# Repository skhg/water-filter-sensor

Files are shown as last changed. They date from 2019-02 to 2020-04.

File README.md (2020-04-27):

# water-filter-sensor
A smart(er) ceramic water filter for my kitchen. This is the second version. [Here](./v1) you can see the first attempt.

## Concept
We use a [ceramic water filter](https://en.wikipedia.org/wiki/Ceramic_water_filter) at home for our drinking water and ice-making. Normally we try to keep it full, so there's always about 2L available at any time. However to be sure we haven't over-filled, we have to remove the top section to see how much is left in the bottom. Obviously, this minor effort is totally unacceptable, so I built a sensor system to tell us how full the tank is.

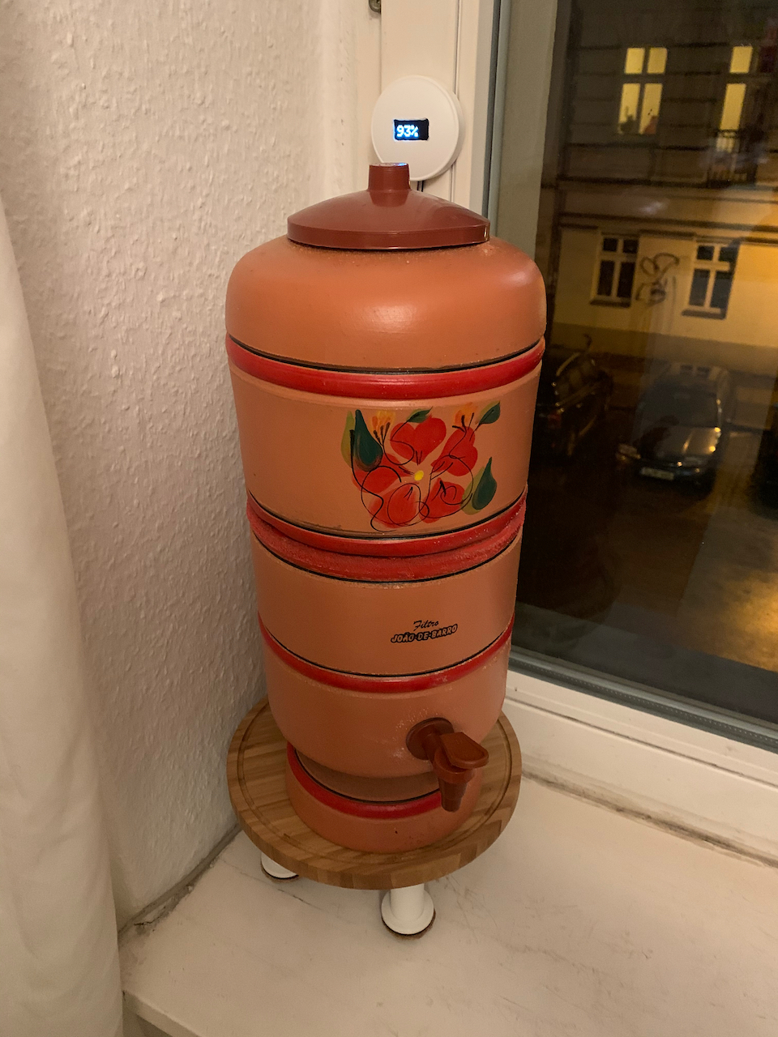
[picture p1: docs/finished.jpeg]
Finished project


Because i'm going totally overboard, it's also WiFi connected, remotely monitored and remotely configurable. Remote config/monitoring is done using my [household data logger](https://github.com/skhg/household-data-logger) project.

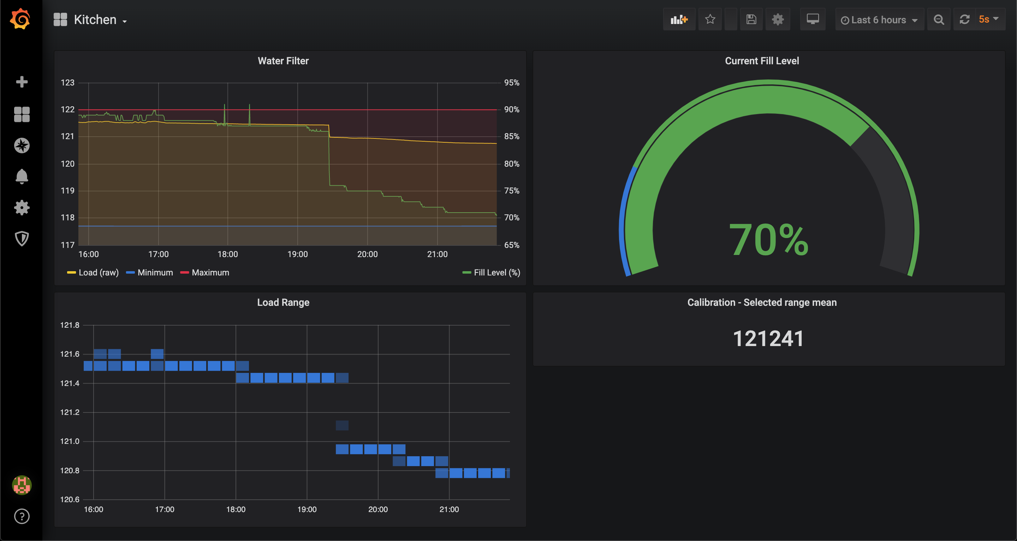
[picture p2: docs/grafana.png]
Grafana dashboard


## Overview
The water filter now sits on top of a circular wooden board, with adjustable legs I found in a waste bin at IKEA. Each leg has a HX-711 compatible load sensor glued to the bottom. Under the board, there's a plastic box to house the electronics. A longer ribbon cable extends up to eye level where a tiny OLED display shows the estimated fill percentage.

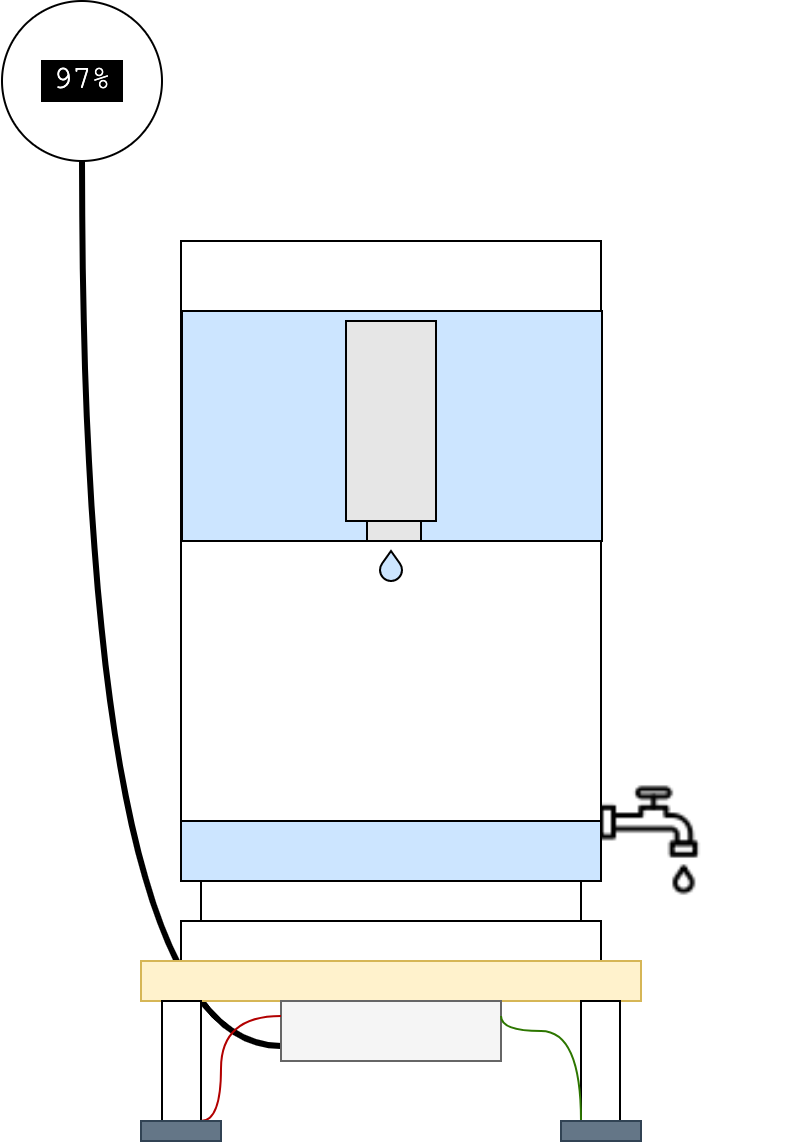
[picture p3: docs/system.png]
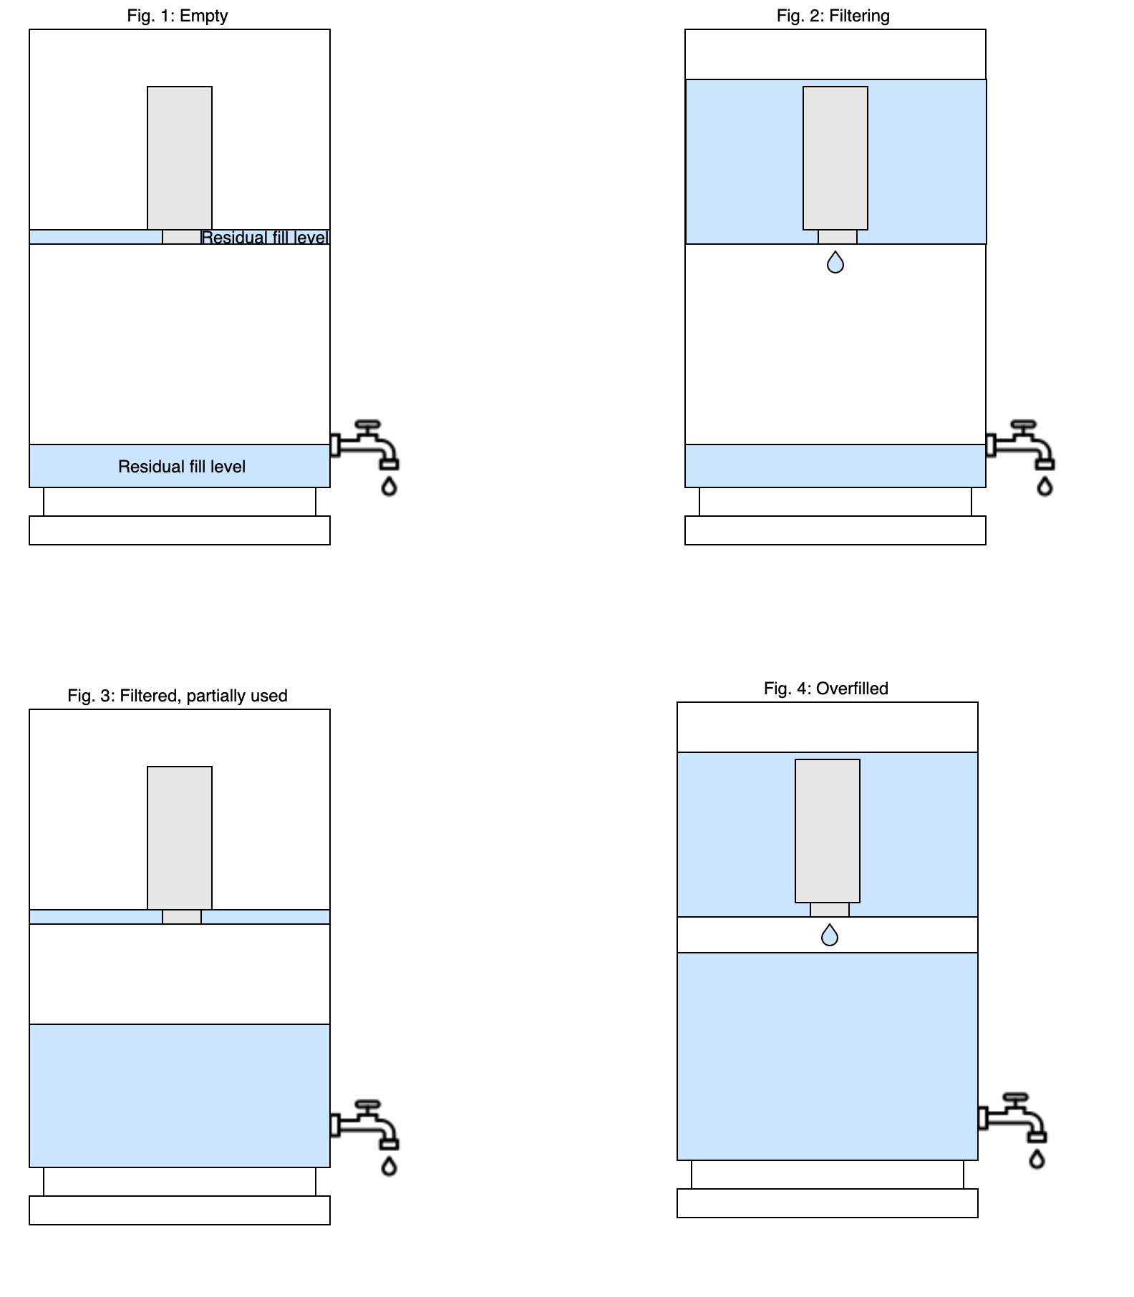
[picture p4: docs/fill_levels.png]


## Materials required
Electronics

* 1 [NodeMCU v3 ESP8266](https://www.amazon.de/-/en/gp/product/B074Q2WM1Y/ref=ppx_yo_dt_b_search_asin_title?ie=UTF8&psc=1)
* 1 HX-711 compatible [load sensor](https://www.amazon.de/gp/product/B075KKH416/ref=ppx_yo_dt_b_asin_title_o03__o00_s00?ie=UTF8&psc=1)
* 1 [OLED Screen](https://www.amazon.de/-/en/gp/product/B01L9GC470/ref=ppx_yo_dt_b_search_asin_title?ie=UTF8&psc=1)
* 1 set of 4 [load cells](https://www.amazon.de/-/en/Weissazi-Personal-Scales-Resistance-Measuring/dp/B07QB2DWMQ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) - I actually got mine from a broken bathroom scales.
* [Ribbon cable](https://www.amazon.de/gp/product/B076CLY8NH/ref=oh_aui_detailpage_o00_s00?ie=UTF8&psc=1)
* [Jumper pin connectors](https://www.amazon.de/gp/product/B01MRSUEHD/ref=oh_aui_detailpage_o01_s00?ie=UTF8&psc=1)

Other:

  * Soldering iron
  * 3rd hand
  * Bamboo board
  * Adjustable legs

## Connecting the load cells

Normally, load cells come with matching wire colours. Unfortunately the ones I scavenged from the old bathroom scale came with different 2 different sets of wire colours, so I had to manually work out which was which.

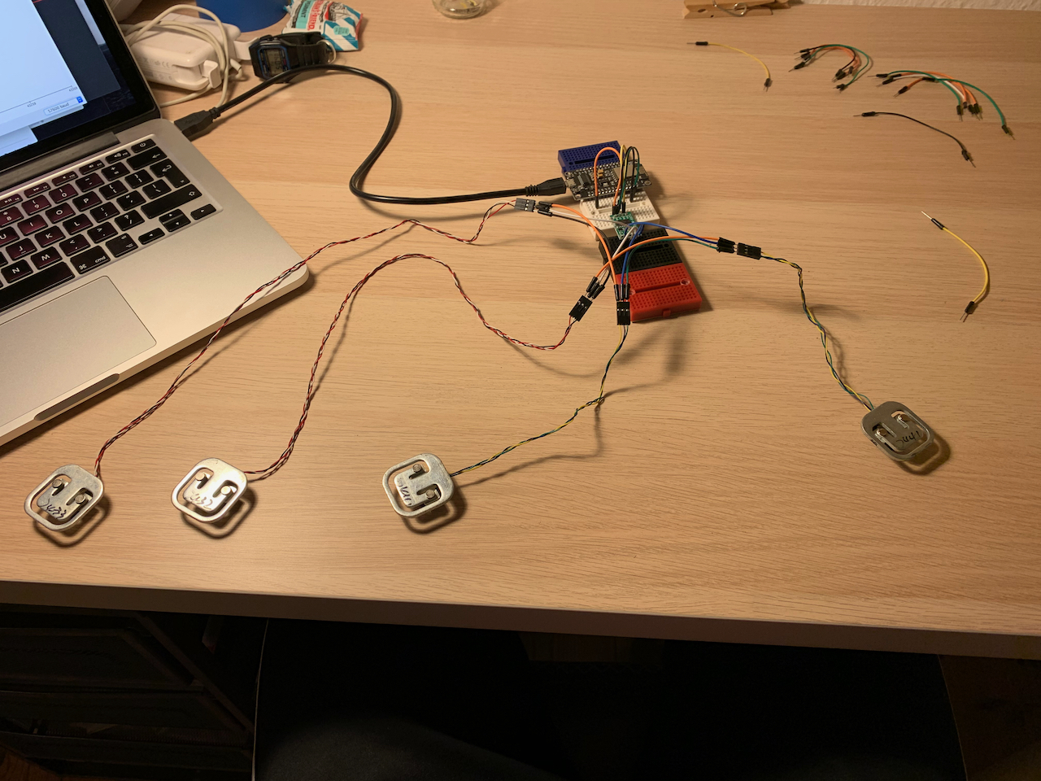
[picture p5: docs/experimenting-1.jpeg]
experimenting


Eventually I found [this diagram](http://blog.medien.ifi.lmu.de/swh/2018/09/10/hx711-how-to-measure-incorrectly/), and manually labelled the wires to match my own:

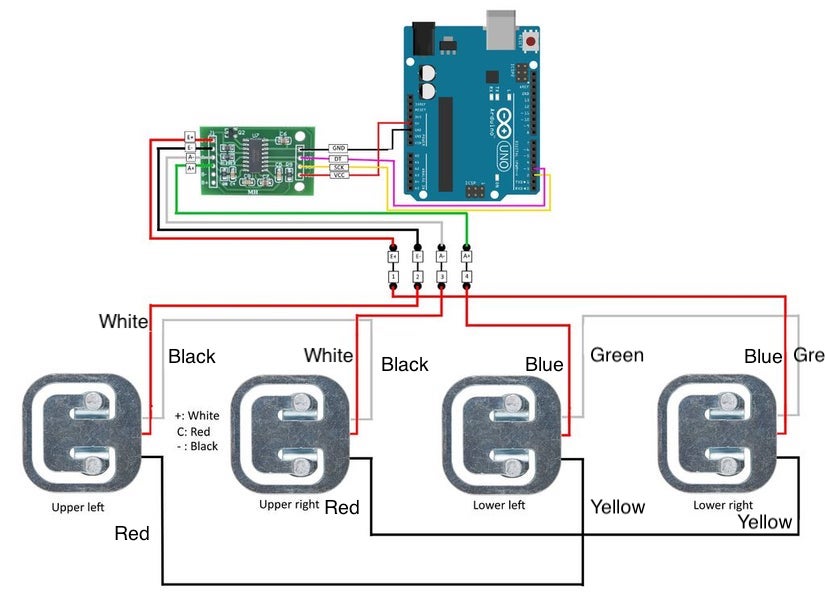
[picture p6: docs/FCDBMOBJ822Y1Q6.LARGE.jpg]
diagram


And got it wired up the same way...
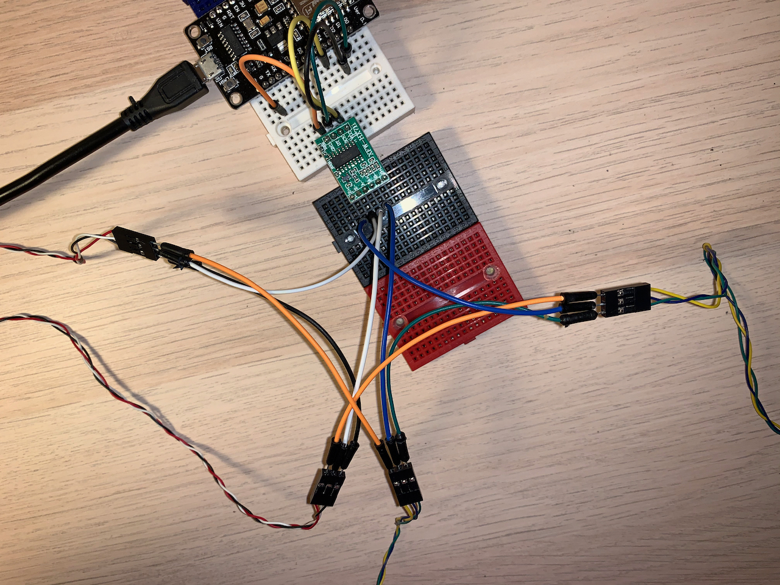
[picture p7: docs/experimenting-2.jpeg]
experimenting


Circuit diagram of the same thing, with the real world wire colours.

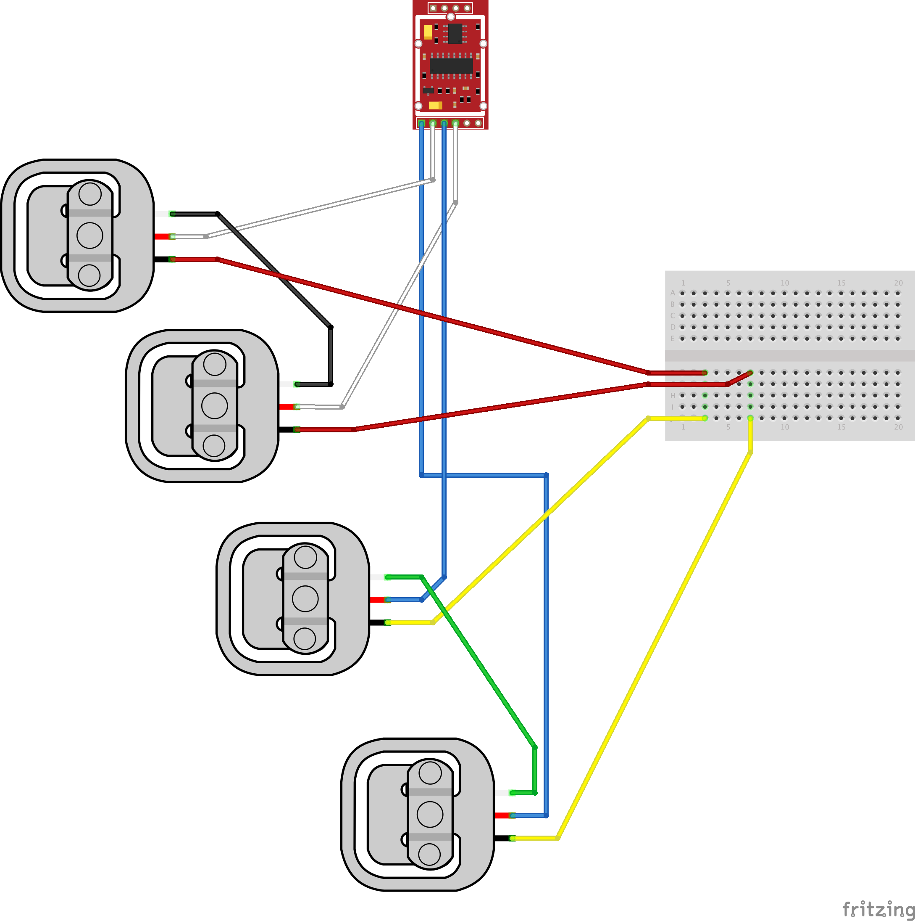
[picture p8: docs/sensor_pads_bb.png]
circuit


## Construction

The 4 sensors (should) evenly distribute the weight between each other. The [flexing](https://en.wikipedia.org/wiki/Load_cell) of the sensor as weight is applied is detected and converted to a load reading.

The load cells need a little space between themselves and the legs I used, so I glued some cork blocks in between, to allow the sensor space to flex.

Everything comes together in a little plastic box to make it a bit more protected from any nearby water splashes. 

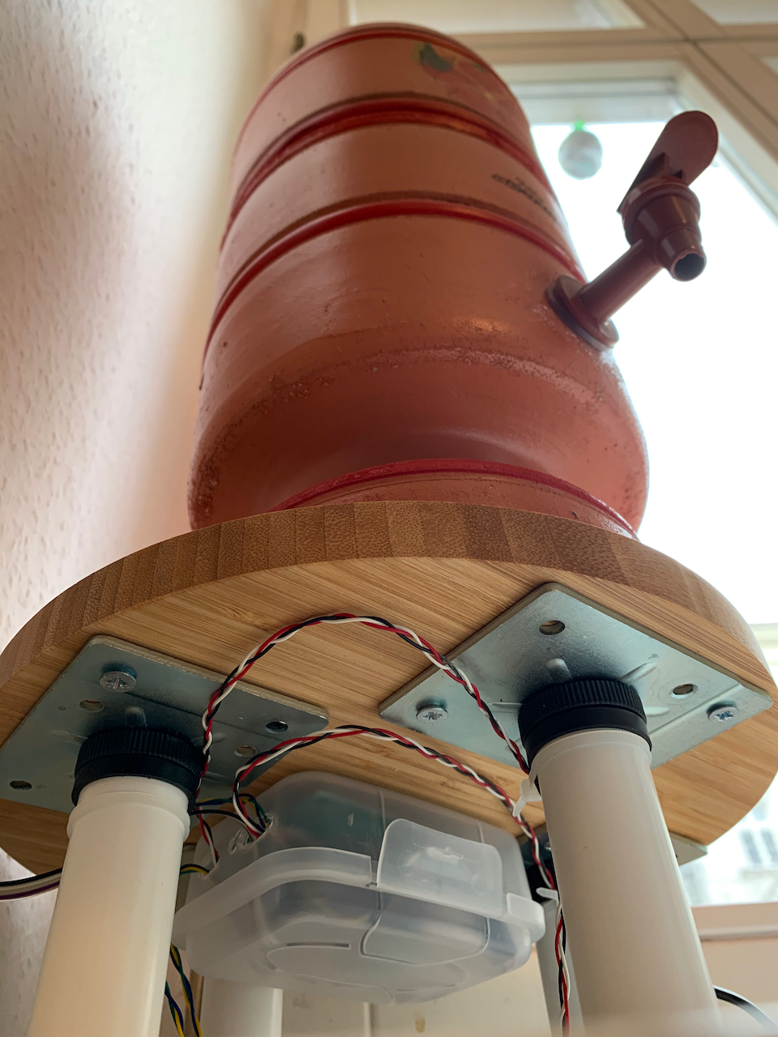
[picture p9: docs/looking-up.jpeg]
looking up


The screen is wedged inside the cap of an old moisturiser jar, just like I used for the [Raspberry Pi killswitch](https://github.com/skhg/raspberrypi-killswitch). These little plastic caps are really versatile for small projects. Since I didn't have any proper tools to cut a hole, I drew a rectangle on the front and melted a hole through it with my soldering iron. Probably toxic and not the best idea.
 
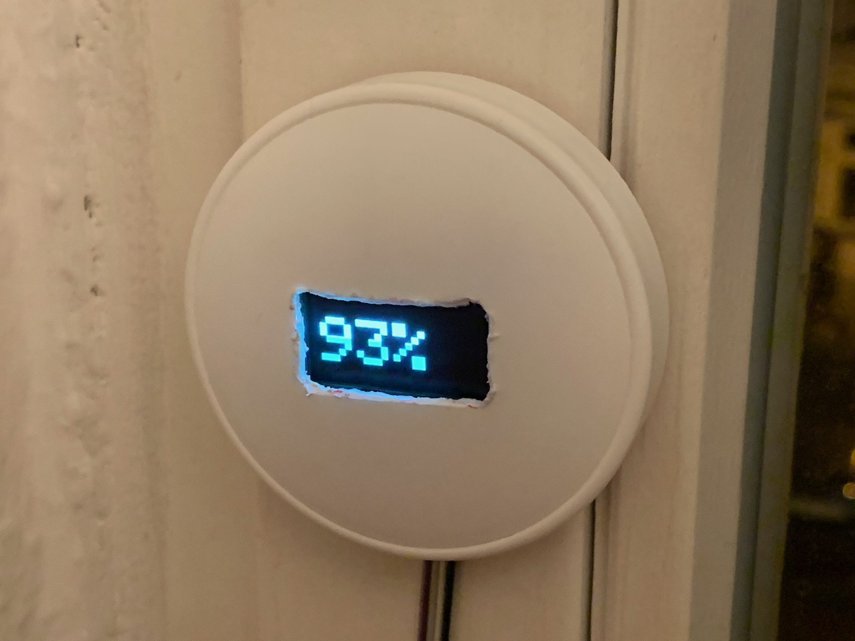
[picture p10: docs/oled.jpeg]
oled


## WiFi connection

### Calibration
For calibration, we need to know what reading the load sensor gives when the tank is empty, and when it's full. Then we can simply get the current reading and work out a percentage of the range. Normally, calibration would mean plugging the board into a laptop over USB, and uploading a new version of the `.ino` sketch with updated high/low values.

So instead, I use a `GET` endpoint on my [household data logger](https://github.com/skhg/household-data-logger) project, to return the current calibration values over HTTP. The filter looks them up automatically so they can be changed at any time. The message received from the server looks like:

```json
{
    "fullLevel" : 121000,
    "emptyLevel" : 117000
}
```

and the filter uses this to reset its own default values each time an update is received.

### Logging
The board also sends back it's current load level to the logger approximately every 2 seconds. This is also done using JSON over HTTP in a format that looks like

```json
{
    "load" : 1234.56,
    "fillPercentage" : 92.24
}
```

I record this in a time-series database and use it to create the Grafana dashboard shown at the top.

## Code
See the full Arduino C++ code in [water-filter-sensor.ino](water-filter-sensor.ino). 

Dependencies:
 * [movingAvg](https://github.com/JChristensen/movingAvg)
 * [Q2HX711](https://github.com/queuetue/Q2-HX711-Arduino-Library)
 * [home_wifi](https://github.com/skhg/home_wifi) configuration
 * [ArduinoJson](https://arduinojson.org/)
 * [ESP8266WiFi](https://github.com/esp8266/Arduino/tree/master/libraries/ESP8266WiFi)
 * [Adafruit_GFX](https://github.com/adafruit/Adafruit-GFX-Library)
 * [Adafruit_SSD1306](https://github.com/adafruit/Adafruit_SSD1306)

## Circuit

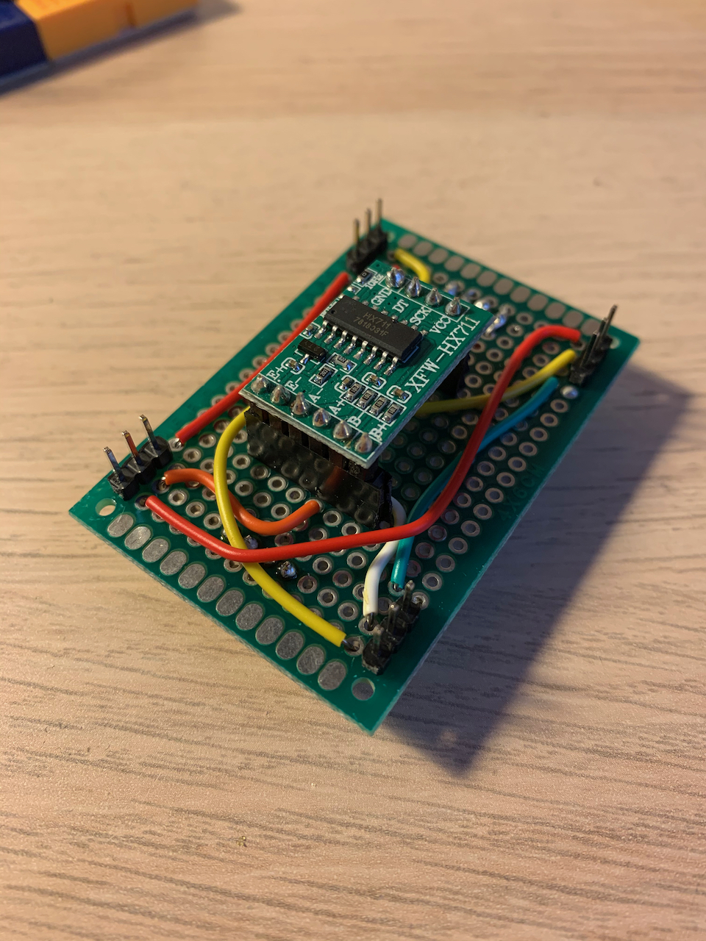
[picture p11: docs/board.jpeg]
board photo Circuit photo


The underside of this has the mounting pins for the Arduino board, but I forgot to take a photo.

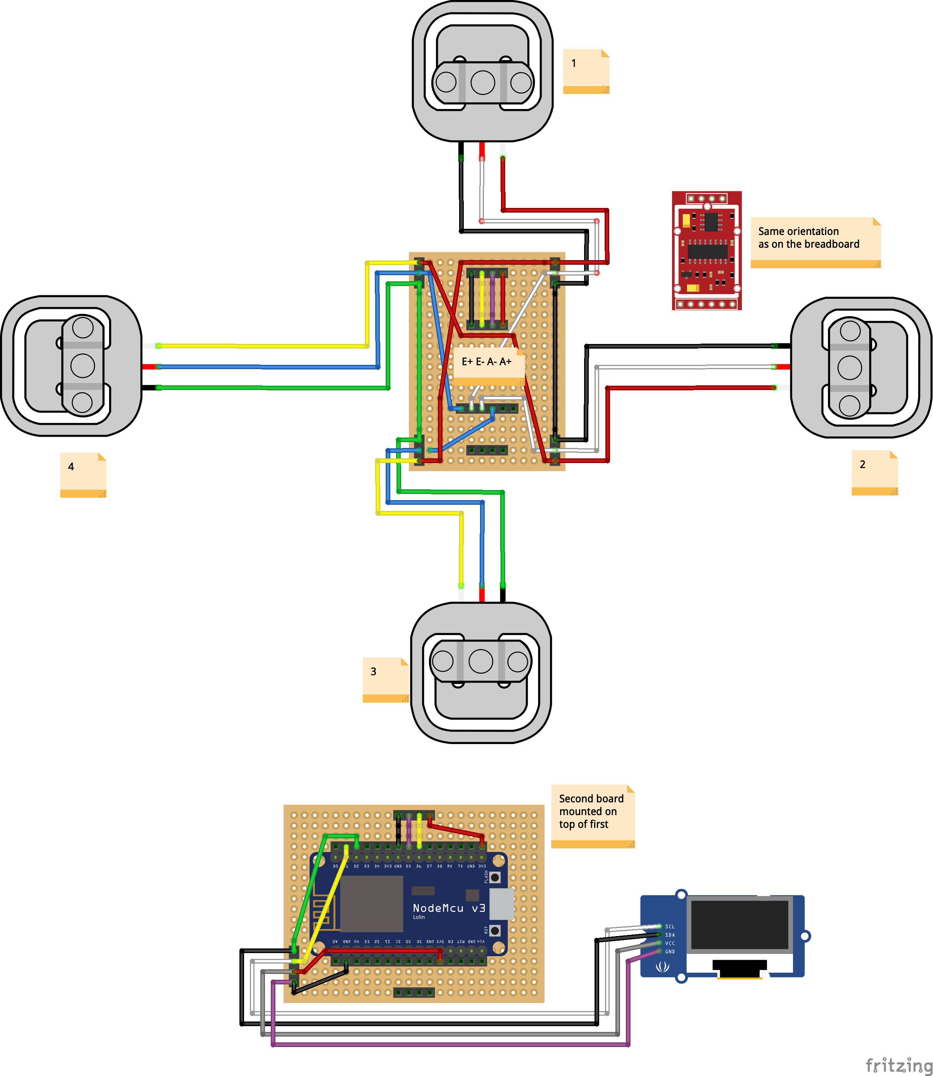
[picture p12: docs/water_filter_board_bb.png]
circuit diagram Circuit diagram


This can also be viewed in the [Fritzing](http://fritzing.org/) software using the [water_filter_board.fzz](./docs/water_filter_board.fzz) file. 

## References
These tutorials proved useful during the project

* [Soldering Tutorial for Beginners: Five Easy Steps](https://www.youtube.com/watch?v=Qps9woUGkvI)
* [How to Remove Solder](https://www.youtube.com/watch?v=-lnRf2biz50)
* [HX711 Load Cell Amplifier Interface with Arduino](https://www.hackster.io/MOHAN_CHANDALURU/hx711-load-cell-amplifier-interface-with-arduino-fa47f3)
* [Load Cell Amplifier HX711 Breakout Hookup Guide](https://learn.sparkfun.com/tutorials/load-cell-amplifier-hx711-breakout-hookup-guide/all)

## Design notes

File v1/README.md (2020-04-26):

# water-filter-sensor (v1)
An indicator light to show the water fill level within a ceramic water filter. This was the first attempt. Refer to arduino code from this commit or before https://github.com/skhg/water-filter-sensor/commit/32b0eb5a3d64f30f886e5c977186836242a59f4d . master branch contains the second effort at doing this.

## Concept
We use a [ceramic water filter](https://en.wikipedia.org/wiki/Ceramic_water_filter) at home for our drinking water and ice-making. Normally we try to keep it full, so there's always about 2L available at any time. However to be sure we haven't over-filled, we have to remove the top section to see how much is left in the bottom. Obviously, this minor effort is totally unacceptable, so I built a sensor system to tell us how full the tank is.

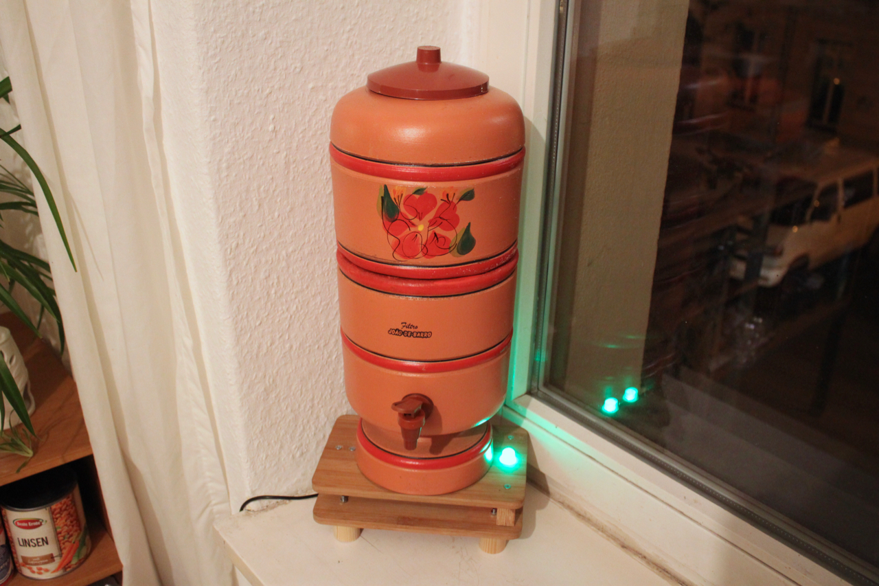
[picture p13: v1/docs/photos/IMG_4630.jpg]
Finished project


## Overview
The water filter now sits on top of a mounting frame, under which there is a HX-711 compatible weight sensor. Alongside the base of the filter, an RGB LED displays different colours to indicate fill level or warning states.

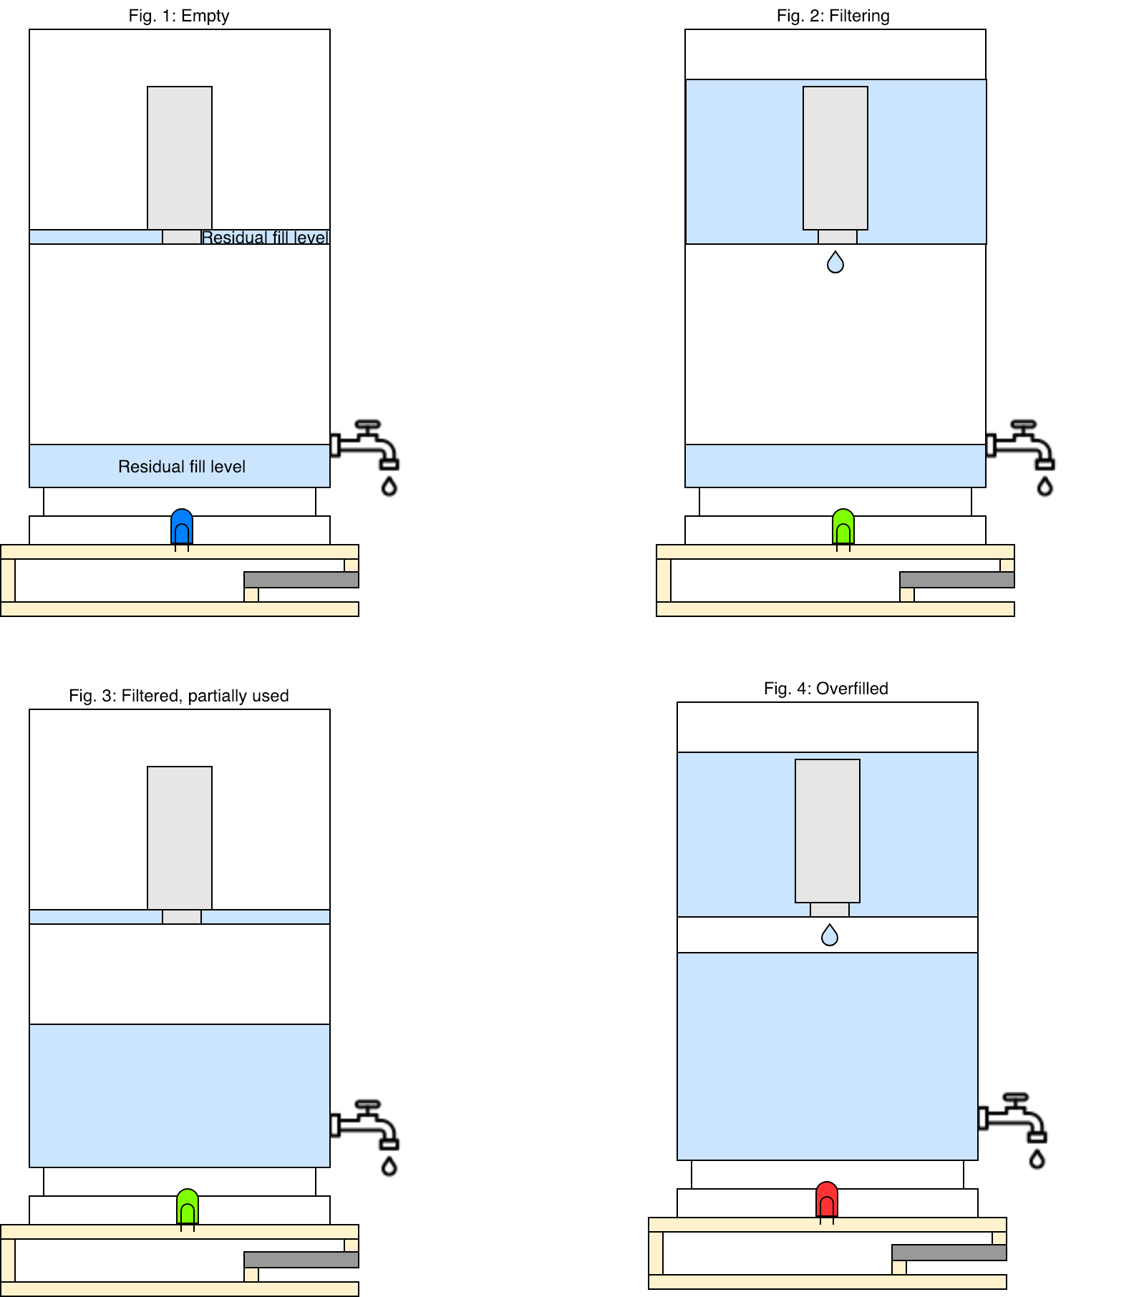
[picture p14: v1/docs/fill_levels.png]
Diagram


## Materials required
Electronics

* 1 [Arduino nano](https://www.amazon.de/gp/product/B01C9J7NGS/ref=ppx_yo_dt_b_asin_title_o02__o00_s00?ie=UTF8&psc=1)
* 1 HX-711 compatible [load sensor](https://www.amazon.de/gp/product/B075KKH416/ref=ppx_yo_dt_b_asin_title_o03__o00_s00?ie=UTF8&psc=1)
* 1 [RGB LED](https://www.conrad.de/de/makerfactory-led-modul-vma307-passend-fuer-arduino-boards-arduino-arduino-uno-fayaduino-freeduino-seeeduino-see-1612767.html)
* [Ribbon cable](https://www.amazon.de/gp/product/B076CLY8NH/ref=oh_aui_detailpage_o00_s00?ie=UTF8&psc=1)
* [Jumper pin connectors](https://www.amazon.de/gp/product/B01MRSUEHD/ref=oh_aui_detailpage_o01_s00?ie=UTF8&psc=1)
* 2 [mini breadboards](https://www.amazon.de/gp/product/B01M9CHKO4/ref=oh_aui_detailpage_o01_s00?ie=UTF8&psc=1)

Other:

  * Soldering iron
  * 3rd hand
  * Small screws (15mm)
  * Small bolts (35mm and 40mm)
  * Bamboo boards
  * Various wooden parts
  * Drill and assorted bits
  * Various small pliers, screwdriver, common tools

## Construction

The sensor must be mounted between two plates in order to work. The [flexing](https://en.wikipedia.org/wiki/Load_cell) of the sensor as weight is applied is detected and converted to a weight reading. I built this out of 2 small bamboo chopping boards, which are light and strong. The rest of the wooden pieces I bought at [Bauhaus](https://www.bauhaus.info/)

### Soldering the HX-711
Many HX-711 sensors come in packs with a board and loose pins. I had never soldered anything except a broken [George Foreman](https://en.wikipedia.org/wiki/George_Foreman_Grill) before this project so it was quite an experience to learn how to do this. Fortunately YouTube is full of tutorial videos. References at the end.

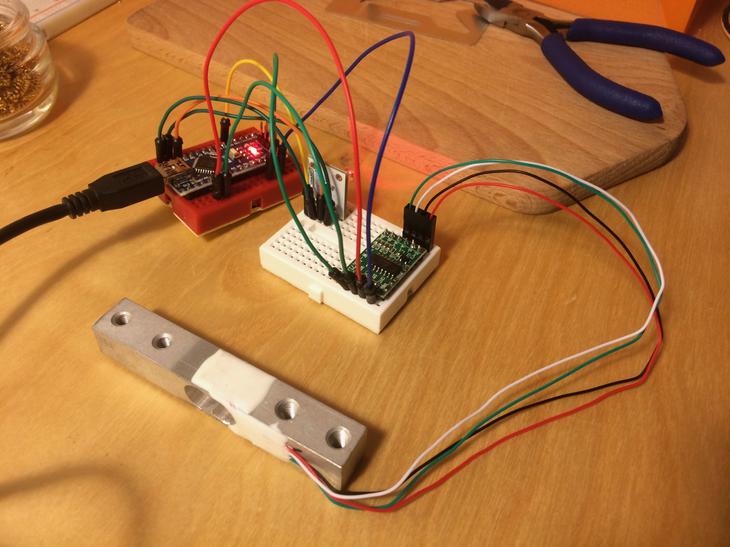
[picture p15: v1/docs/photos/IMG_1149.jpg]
HX711 Bare sensor


### Lower board

The lower board has four 3cm legs attached to keep it above any water that might collect on the counter. Near the centre it has two drilled holes to support the lower side of the sensor, which sits atop a small wooden block. On one side, a wider beam of wood provides a hinge to support half the filter's weight, and reduce the load on the sensor. This beam has some indentations to allow space for the LED module, and holes to fit in bolts that will hold on the top board.

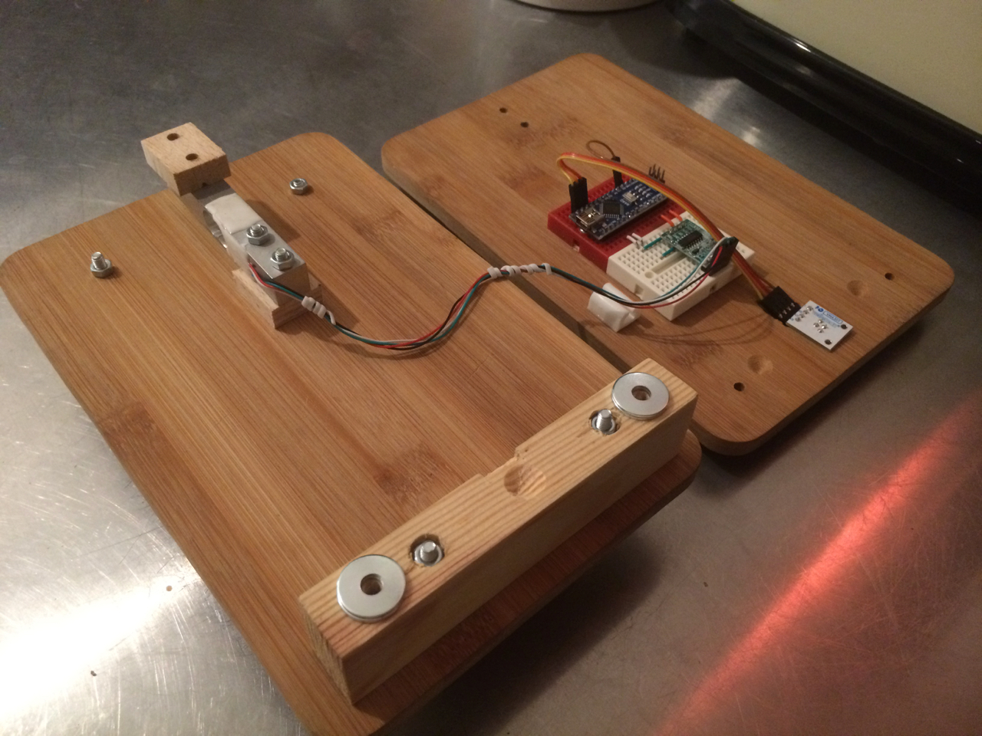
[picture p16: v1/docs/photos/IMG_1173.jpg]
Unfolded Unfolded base


### Upper board

This board will seat the filter, so on top it has four small wooden blocks to provide alignment for the filter's base. The filter should be aligned centrally so the weight is evenly distributed between the sensor and the supporting beam. Otherwise recalibration would be needed every time the filter is moved. On one side two holes fit the bolts that connect the top board to the other side of the sensor. On the other side is the large hole where the LED will poke through.

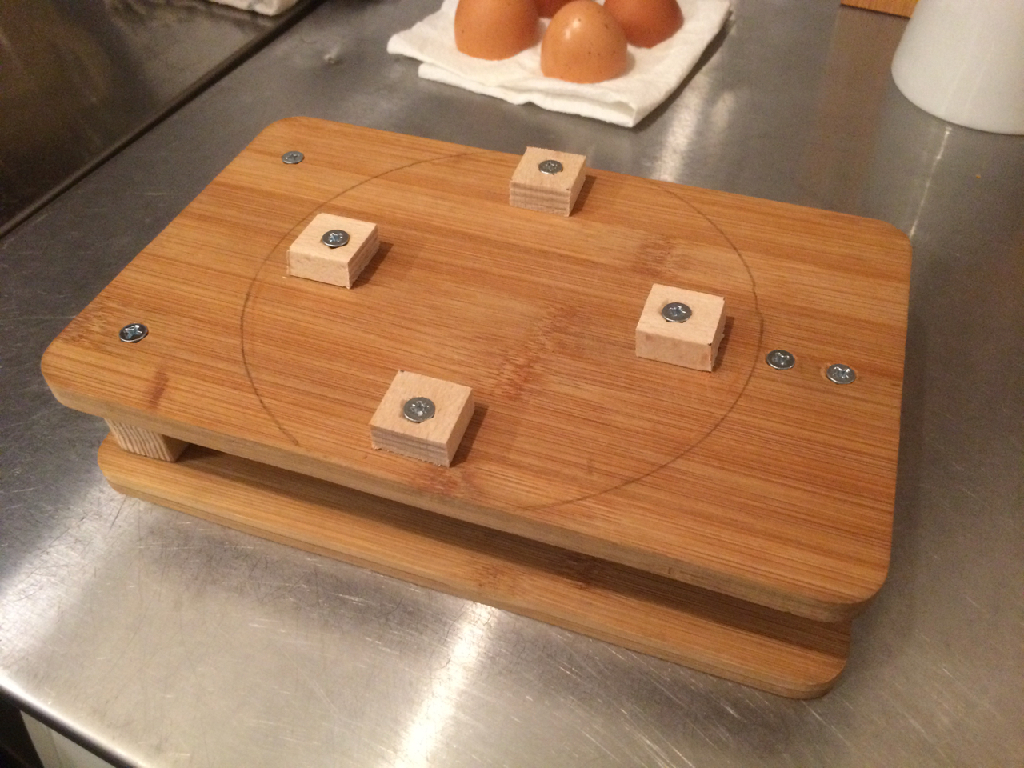
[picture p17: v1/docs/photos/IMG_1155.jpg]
Top alignment points Alignment points


On the underside, two mini breadboards hold the Arduino, the HX-711 board, and their connections. They're attached to the board with narrow bolts so their position could be adjusted later. On the side which sits above the support beam, the LED hole has a chunk taken out near it, to allow the module and connecting cables space to fit.

### Mounting

After bolting together the boards and tidying the cables out of the way, the water filter can be sat on top. Nice.

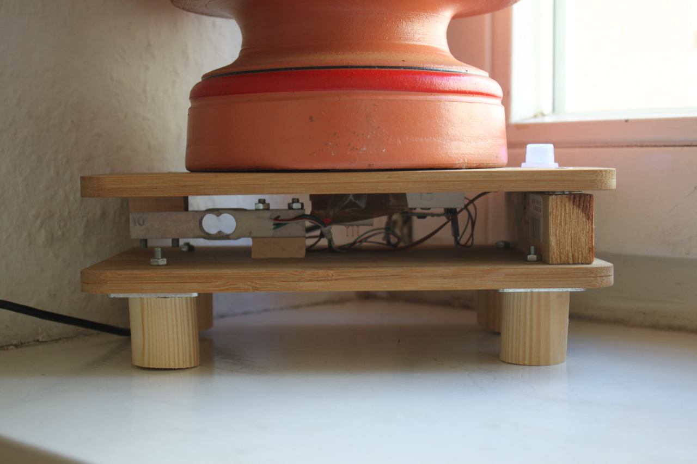
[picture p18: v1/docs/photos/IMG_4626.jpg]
Mounted


## Code
See the full Arduino C++ code in [water-filter-sensor.ino](water-filter-sensor.ino). 

Dependencies:
 * [movingAvg](https://github.com/JChristensen/movingAvg)
 * [Q2HX711](https://github.com/queuetue/Q2-HX711-Arduino-Library)

## Circuit

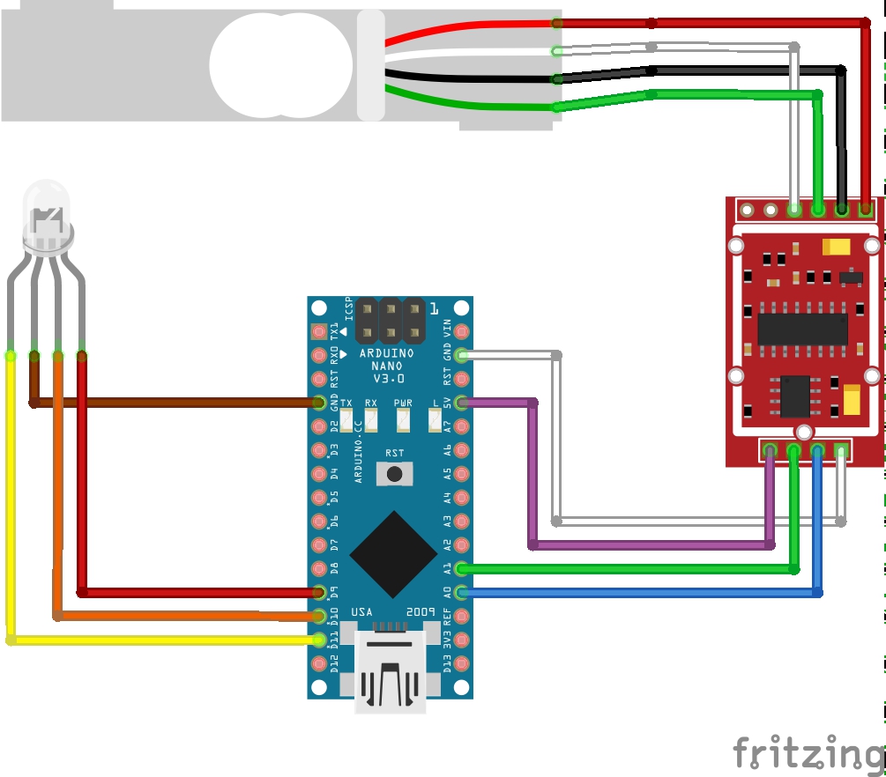
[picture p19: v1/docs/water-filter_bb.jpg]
Circuit diagram


This can also be viewed in the [Fritzing](http://fritzing.org/) software using the [water-filter.fzz](water-filter.fzz) file. 

## Calibration

Depending on the tension in the bolts connecting the board, sensor and support beam, the force applied to the sensor may vary quite a lot. It's important to recalibrate the sensor after taking the system apart or changing it's location.

By enabling `DEBUG` mode and viewing the output we can determine what the sensor reads when the tanks are full or empty, and use this to change the parameters defined at the top of [water-filter-sensor.ino](water-filter-sensor.ino).

Debug output also prints static lines which can be viewed in the Arduino [plotter](https://learn.adafruit.com/experimenters-guide-for-metro/circ08-using%20the%20arduino%20serial%20plotter) to show the various limits or trigger levels that have been set. Filling and emptying the tank can easily show how the level varies in the real-time graph.

### Configuration

Many other configuration options are available at the top of [water-filter-sensor.ino](water-filter-sensor.ino) including relative LED brightness, smoothness or accuracy of sensor data, and at what levels you want to get high/low water alerts. 

## References
These tutorials proved useful during the project

* [Soldering Tutorial for Beginners: Five Easy Steps](https://www.youtube.com/watch?v=Qps9woUGkvI)
* [How to Remove Solder](https://www.youtube.com/watch?v=-lnRf2biz50)
* [HX711 Load Cell Amplifier Interface with Arduino](https://www.hackster.io/MOHAN_CHANDALURU/hx711-load-cell-amplifier-interface-with-arduino-fa47f3)
* [Load Cell Amplifier HX711 Breakout Hookup Guide](https://learn.sparkfun.com/tutorials/load-cell-amplifier-hx711-breakout-hookup-guide/all)

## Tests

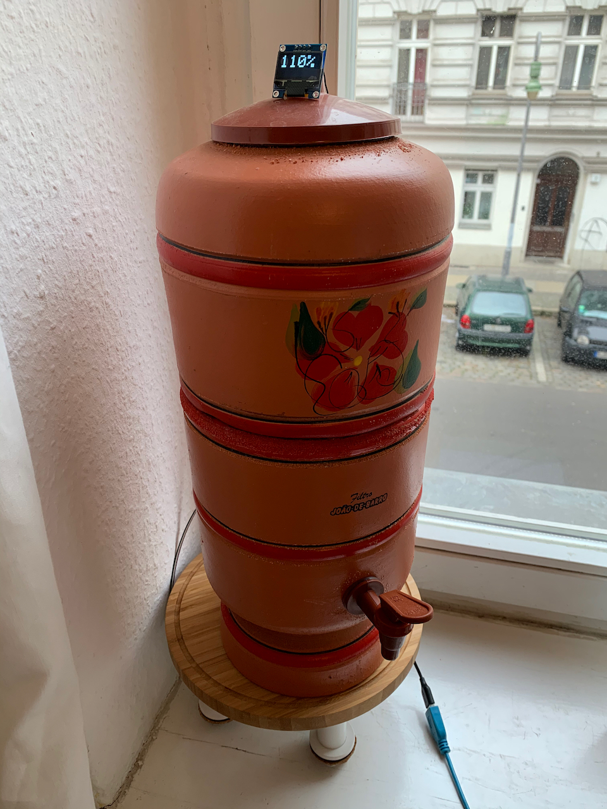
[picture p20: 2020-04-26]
docs/filter-testing.jpeg

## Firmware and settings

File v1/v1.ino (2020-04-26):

/*
 * CALIBRATION VALUES
 * 
 * All of these must be reset after disassembling and reassembling the base.
 */

/*
 * Turn on debug output to allow for calibration. Turn off to stop the TX LED flashing
 * 
 * Values format:
 * MINIMUM_WATER_LEVEL, LOW_SAFE_LEVEL, HIGH_SAFE_LEVEL, MAXIMUM_WATER_LEVEL, CURRENT_WEIGHT, CURRENT_WEIGHT_SMOOTHED_AVERAGE
 */
const boolean DEBUG_ON = false;

/*
 * The maximum weight of the system. Above this level, water will overflow.
 * 
 * (Residual in top tank + full lower tank)
 */
const int MAXIMUM_WATER_LEVEL = 9345;

/*
 * The weight of the system when tap no longer flows out.
 * 
 * (Residual in top tank + residual in lower tank)
 */
const int MINIMUM_WATER_LEVEL = 9179;








/*
 * USER PREFERENCES
 * 
 * Settings which can be adjusted depending on the desired display
 */

/*
 * The fractional fill level (0.0 to 1.0) below which we should alert to refill (Blue flashing)
 */
const double LOW_SAFE_WATER_FRACTION = 0.3;

/* 
 * The highest fractional fill level (0.0 to 1.0) we aim to reach when we refill
 */
const double HIGH_SAFE_WATER_FRACTION = 0.8;

/*
 * How many values to use for smoothing out the data and forming a moving average
 */
const int MOVING_AVERAGE_BUCKET_SIZE = 20;








/*
 * SYSTEM CONFIGURATION
 * 
 * How the Arduino's physical devices are set up.
 */

/*
 * Pin positions for the RGB LED. These must be connected to PWM pins in order to vary brightness
 * 
 * PWM pin locations:
 * https://www.arduino.cc/reference/en/language/functions/analog-io/analogwrite/
 */
#define BLUE_LED 9
#define GREEN_LED 10
#define RED_LED 11

/*
 * Pin positions for the HX-711 load sensor
 * 
 * These must be connected to analogue input pins.
 * 
 * Analogue input pins:
 * https://www.arduino.cc/reference/en/language/functions/analog-io/analogread/
 */
#define LOAD_SENSOR_DATA A0
#define LOAD_SENSOR_CLOCK A1

/*
 * LED total brightness factor
 * 
 * If your LED is too bright, reduce this value (0.0 to 1.0)
 */
const double LED_MASTER_SCALE = 1.0;

/*
 * LED relative brightness factors
 * 
 * Each of the RGB LED's components may appear to be slightly brighter than the others.
 * Set the dimmest LED to 1.0 and adjust the others accordingly (0.0 to 1.0)
 * 
 */
const double LED_BLUE_SCALE = 0.2;
const double LED_RED_SCALE = 1;
const double LED_GREEN_SCALE = 0.25;

/*
 * Load sensor read interval
 * 
 * Reading the load sensor may take a few milliseconds and doing this on each cycle may be unnecessary.
 * This value allows you to read the sensor every n'th cycle
 */
const int LOAD_SENSOR_READ_INTERVAL = 100;

/*
 * Loop delay in milliseconds
 * 
 * If your LED flashes too quickly or too slowly, adjusting this value will change the delay until the next cycle.
 */
const int LOOP_DELAY = 1;





 

/*
 * APPLICATION CODE
 * 
 * No need to make any changes below here
 */

#include <movingAvg.h>
#include <Q2HX711.h>

Q2HX711 load_sensor(LOAD_SENSOR_DATA, LOAD_SENSOR_CLOCK);

movingAvg smooth_weight(MOVING_AVERAGE_BUCKET_SIZE);

int low_safe_level;
int high_safe_level;
  
//state used only for controlling light pulse cycle
int pulse_brightness = 0;    // how bright the LED is during current cycle
int fadeAmount = 1;    // how many points to fade the LED by

//state used to determine when to read the weight sensor
int sensor_cycle = 0; // Current state of the cycle for sensor reading

void setup() {

  int range = MAXIMUM_WATER_LEVEL - MINIMUM_WATER_LEVEL;
  low_safe_level = (range * LOW_SAFE_WATER_FRACTION) + MINIMUM_WATER_LEVEL;
  high_safe_level = (range * HIGH_SAFE_WATER_FRACTION) + MINIMUM_WATER_LEVEL;
  
  // LED pins are all outputs
  pinMode(BLUE_LED, OUTPUT);
  pinMode(GREEN_LED, OUTPUT);
  pinMode(RED_LED, OUTPUT);

  Serial.begin(9600);

  smooth_weight.begin();
}

int readWeight() {

  if(sensor_cycle == LOAD_SENSOR_READ_INTERVAL){
    if(sensor_cycle >= LOAD_SENSOR_READ_INTERVAL){
      sensor_cycle = 0;
    }

    int curr_weight = (load_sensor.read() / 1000);
    smooth_weight.reading(curr_weight);

    if(DEBUG_ON){
      Serial.print(MINIMUM_WATER_LEVEL);
      Serial.print(",");
      Serial.print(low_safe_level);
      Serial.print(",");
      Serial.print(high_safe_level);
      Serial.print(",");
      Serial.print(MAXIMUM_WATER_LEVEL);
      Serial.print(",");
      Serial.print(curr_weight);
      Serial.print(",");
      Serial.println(smooth_weight.getAvg());
    }
    
  }

  sensor_cycle++;
    
  return smooth_weight.getAvg();

}

void bluePulse() {
  rgbPulse(false, false, true);
}

void solidGreen() {
  rgbSolid(false, true, false);
}

void solidBlue() {
  rgbSolid(false, false, true);
}

void redPulse() {
  rgbPulse(true, false, false);
}

void setColours(boolean red, boolean green, boolean blue, int brightness) {
  if(blue) {
    analogWrite(BLUE_LED, brightness * LED_MASTER_SCALE * LED_BLUE_SCALE);
  }else{
    analogWrite(BLUE_LED, 0);
  }
  if(red) {
    analogWrite(RED_LED, brightness * LED_MASTER_SCALE * LED_RED_SCALE);
  }else{
    analogWrite(RED_LED, 0);
  }
  if(green) {
    analogWrite(GREEN_LED, brightness * LED_MASTER_SCALE * LED_GREEN_SCALE);
  }else{
    analogWrite(GREEN_LED, 0);
  }
}

void rgbSolid(boolean red, boolean green, boolean blue) {
  int full_brightness = 255;
  
  setColours(red, green, blue, full_brightness);
}

void rgbPulse(boolean red, boolean green, boolean blue) {

  setColours(red, green, blue, pulse_brightness);
  
  // change the brightness for next time through the loop:
  pulse_brightness = pulse_brightness + fadeAmount;

  // reverse the direction of the fading at the ends of the fade:
  if (pulse_brightness <= 0 || pulse_brightness >= 255) {
    fadeAmount = -fadeAmount;
  }
}

void loop() {

  int current_weight = readWeight();

  if(current_weight <= low_safe_level) {
    bluePulse();
  } else if(current_weight > low_safe_level && current_weight <= high_safe_level) {
    solidBlue();
  } else if(current_weight > high_safe_level && current_weight <= MAXIMUM_WATER_LEVEL) {
    solidGreen();
  } else if(current_weight > MAXIMUM_WATER_LEVEL) {
    redPulse();
  }

  delay(LOOP_DELAY);

}

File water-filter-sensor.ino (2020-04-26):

/*
 * CALIBRATION VALUES
 */

/*
 * Turn on debug output to allow for console calibration.
 * 
 * Values format:
 * MINIMUM_WATER_LEVEL, MAXIMUM_WATER_LEVEL, CURRENT_WEIGHT, CURRENT_WEIGHT_SMOOTHED_AVERAGE
 */
const boolean DEBUG_ON = true;

/*
 * The maximum weight of the system. Above this level, water will overflow.
 * This is a default value which is updated at first connection to the data logger.
 * 
 * (Residual in top tank + full lower tank)
 */
int MAXIMUM_WATER_LEVEL = 121000;

/*
 * The weight of the system when tap no longer flows out. Updated by the data logger.
 * This is a default value which is updated at first connection to the data logger.
 * 
 * (Residual in top tank + residual in lower tank)
 */
int MINIMUM_WATER_LEVEL = 117000;








/*
 * USER PREFERENCES
 * 
 * Settings which can be adjusted depending on the desired display
 */

/*
 * How many values to use for smoothing out the data and forming a moving average
 */
const int MOVING_AVERAGE_BUCKET_SIZE = 20;

/**
 * IP Address and port to send data to
 */
#define IP_1 192
#define IP_2 168
#define IP_3 178
#define IP_4 29
#define IP_PORT 8080









/*
 * SYSTEM CONFIGURATION
 * 
 * How the Arduino's physical devices are set up.
 */

/*
 * Pin positions for the HX-711 load sensor
 * 
 * These must be connected to analogue input pins.
 * 
 * Analogue input pins:
 * https://www.arduino.cc/reference/en/language/functions/analog-io/analogread/
 */
#define LOAD_SENSOR_DATA 14  // D5 on NodeMCU ESP8266 Lolin v3
#define LOAD_SENSOR_CLOCK 12 // D6 on NodeMCU ESP8266 Lolin v3

/*
 * Load sensor read interval
 * 
 * Reading the load sensor may take a few milliseconds and doing this on each cycle may be unnecessary.
 * This value allows you to read the sensor every n'th cycle
 */
const int LOAD_SENSOR_TRANSMIT_INTERVAL = 50;

/*
 * Screen dimensions and setup
 */
#define SCREEN_WIDTH 128 // OLED display width, in pixels
#define SCREEN_HEIGHT 64 // OLED display height, in pixels
#define OLED_RESET -1 // Reset pin # (or -1 if sharing Arduino reset pin)

/**
 * Delay before reboot
 */
#define REBOOT_DELAY_MS 1000

/**
 * How many seconds to wait before WiFi connection is established, or the system will reboot
 */
#define WIFI_CONNECT_TIMEOUT_SECONDS 30



 

/*
 * APPLICATION CODE
 * 
 * No need to make any changes below here
 */

#include <movingAvg.h>
#include "HX711.h"
#include <ArduinoJson.h>
#include <SPI.h>
#include <Wire.h>
#include<ESP8266WiFi.h> 
#include<home_wifi.h>
#include <Adafruit_GFX.h>
#include <Adafruit_SSD1306.h>

HX711 load_sensor;
WiFiClient client;
IPAddress server(IP_1,IP_2,IP_3,IP_4);
movingAvg smooth_weight(MOVING_AVERAGE_BUCKET_SIZE);
StaticJsonDocument<200> doc;

Adafruit_SSD1306 display(SCREEN_WIDTH, SCREEN_HEIGHT, &Wire, OLED_RESET);
int transmit_cycle = LOAD_SENSOR_TRANSMIT_INTERVAL;


void setup() {
  Serial.begin(115200);

  setupScreen();
  drawText("Booting...", 3);
  
  int range = MAXIMUM_WATER_LEVEL - MINIMUM_WATER_LEVEL;

  delay(1000); // Give the weight sensor a moment to initialise
  
  smooth_weight.begin();
  load_sensor.begin(LOAD_SENSOR_DATA, LOAD_SENSOR_CLOCK);

  while(!load_sensor.is_ready()){
    Serial.println("Waiting for load sensor...");
    delay(1000);
  }
}

void setupScreen() {
  
  if(!display.begin(SSD1306_SWITCHCAPVCC, 0x3C)) {
    Serial.println(F("SSD1306 allocation failed"));
    for(;;); // Don't proceed, loop forever
  }
}

int readWeight() {

  if (load_sensor.is_ready()) {
    int curr_weight = (load_sensor.read() / 10);
    smooth_weight.reading(curr_weight);
  
    if(DEBUG_ON){
      Serial.print(MINIMUM_WATER_LEVEL);
      Serial.print(",");
      Serial.print(MAXIMUM_WATER_LEVEL);
      Serial.print(",");
      Serial.print(curr_weight);
      Serial.print(",");
      Serial.println(smooth_weight.getAvg());
    }
  }
    
  return smooth_weight.getAvg();
}

void drawText(String text, int textSize) {
  display.clearDisplay();

  display.setTextSize(textSize);
  display.setCursor(0,20);
  display.setTextColor(SSD1306_WHITE);
  display.println(text);

  display.display();
  delay(50); // Delay added because writing to the screen too frequently causes it not to update at all
}

int getCurrentFillPercent(int current_weight) {
  if(current_weight <= MINIMUM_WATER_LEVEL){
    return 0; // Negative fill percentages don't make sense - usually this will occur only when the top tank is taken off
  }

  double fraction = ((double)current_weight - (double)MINIMUM_WATER_LEVEL) / ((double)MAXIMUM_WATER_LEVEL - (double)MINIMUM_WATER_LEVEL) * 100;

  return (int)fraction;
}

void loop() {
  connectToWifi();

  int currentWeight = readWeight();
  int fillPercent = getCurrentFillPercent(currentWeight);

  String percentText = String(fillPercent) + "%";
    
  drawText(percentText, 5);

  transmitReading(currentWeight, fillPercent);
}

void transmitReading(int weight, int fillPercent) {

  if(transmit_cycle == LOAD_SENSOR_TRANSMIT_INTERVAL){
    if(transmit_cycle >= LOAD_SENSOR_TRANSMIT_INTERVAL){
      transmit_cycle = 0;
    }

    // Get the latest configuration for high/low levels and update if necessary
    if (client.connect(server, IP_PORT)) {      
      client.print("GET /kitchen/water-filter/configuration HTTP/1.1\r\nHost: hallway\r\nConnection: close\r\n\r\n");

      String httpConversation = "";      
      while (client.connected() || client.available())
      {
        if (client.available())
        {
          httpConversation += client.readStringUntil('\n');
        }
      }
      client.stop();

      String allJson = httpConversation.substring(httpConversation.indexOf('{'), httpConversation.indexOf('}') + 1);
      Serial.println(allJson);

      deserializeJson(doc, allJson);
      MAXIMUM_WATER_LEVEL = doc["fullLevel"];
      MINIMUM_WATER_LEVEL = doc["emptyLevel"];
      
    }else{
      Serial.println("ERROR: Failed to connect");
      reboot();
    }

    // Try to send the latest reading to the logger
    if (client.connect(server, IP_PORT)) {      
      // Make a HTTP request:
      String json = "{\"load\":"+String(weight)+",\"fillPercentage\":"+String(fillPercent)+"}";
      client.println("POST /kitchen/water-filter HTTP/1.0");
      client.println("Content-Type: application/json");
      client.print("Content-Length: ");
      client.println(json.length());
      client.println();
      client.println(json);
      client.println();
      client.stop();
    }else{
      Serial.println("ERROR: Failed to connect");
      reboot();
    }
    
  }

  transmit_cycle++; 
}

void reboot(){
  delay(REBOOT_DELAY_MS);
  Serial.println("Rebooting...");
  ESP.restart();
}
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

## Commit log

2019-01-25 add basic diagram
    [water-filter.fzz]
2019-01-25 add sketch but without input from weight sensor
2019-02-02 updated for usage of the real sensor
    [water-filter.fzz]
2019-02-02 add a tare value and print out smoothed and live values
2019-02-03 change pin order
    [water-filter.fzz]
2019-02-03 wire colours
    [water-filter.fzz]
2019-02-03 handle slow sensor reading by skipping for most cycles
    [water-filter-sensor.ino]
2019-02-04 calibrate and add values for full and empty states
2019-02-10 sensor photo
2019-02-10 image of mounted filter
2019-05-12 using wifi enabled version now
    [water-filter.fzz]
2020-04-26 Four legged sensor with OLED (#1)
    * four legged sensor with OLED
    * add a booting message and clean up old code
    * wifi connection and nicer information on startup, sending raw and percentage to the data logger
    * ignore intelliJ and prepare for remote reconfig
    * get config from logger and more comments
    * archive the old version
    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
    [sensor_pads.fzz, tinyscreen.fzz, water-filter.fzz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]
